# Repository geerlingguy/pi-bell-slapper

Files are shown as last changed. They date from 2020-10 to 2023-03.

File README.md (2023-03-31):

# Raspberry Pi Bell Slapper

_a.k.a. "The King of Ding", harbinger of the Internet of Dings_



<p align="center">
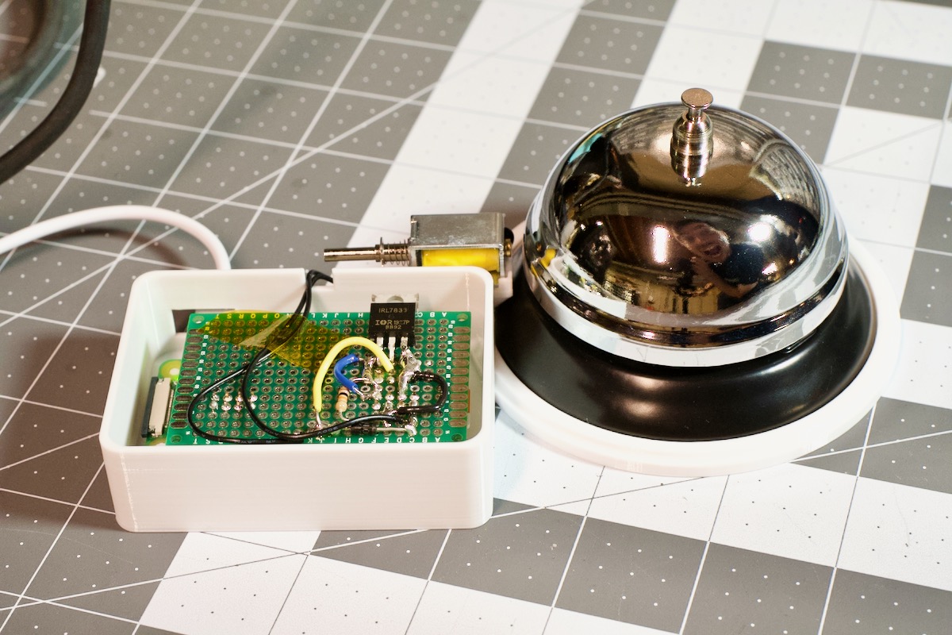
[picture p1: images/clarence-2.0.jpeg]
Clarence 2.0 - Raspberry Pi Bell Slapper
  
</p>

Why? I need a Raspberry Pi to slap a bell in response to a particular trigger.

In my case, it's for a radiothon. When a nonprofit community radio station gets a phone call, you can hear the phone in the background. When they get an online donation, you hear nothing.

Something is better than nothing, so I made this project, which slaps a bell upon a triggering condition.

## Is there a video of the build process?

Why, yes! How did you know?

Watch these videos for more on the build:

  - [The Raspberry Pi Internet of Dings Notification Bell](https://www.youtube.com/watch?v=o5wOzNzShrA) (June 2021 - "Clarence 2.0")
  - [The Raspberry Pi Bell Slapper - a software-controlled bell](https://www.youtube.com/watch?v=Etr7uIL9spg) (December 2020 - "Bell Slapper Mark I")

## How is the bell slapped?

I thought you'd never ask!

The bell is hit by a solenoid, specifically the [uxcell 4.5V mini Push-Pull Solenoid](https://amzn.to/2UkcLvh) I bought from Amazon.

<p align="center">
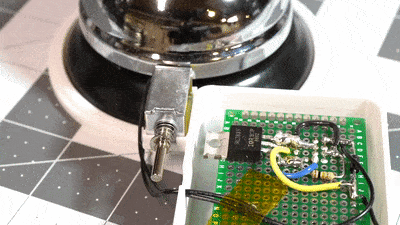
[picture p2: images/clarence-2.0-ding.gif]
Clarence 2.0 - Raspberry Pi Bell Slapper Solenoid Ding
  
</p>

The Pi tells the solenoid to trigger, and a little circuit I built as a hacked-together Pi HAT fires off a short pulse of energy to hit the side of the bell directly.

> In 2020, the original "Mark I" version of the bell was slapped quite differently, using a servo. Read the [Mark I README](README-Mark-I.md) for more information about _that_ version of the bell.

## What kind of bell does it slap?

I'm currently slapping a boring old call bell. [This call bell](https://amzn.to/3iCUL5F). But any bell you could mount to be slapped would work.

## How do I slap a bell?

I'm glad you asked! You'll need to gather some parts and solder together a little control circuit, since the Pi can't drive a 1A solenoid directly through a GPIO pin.

### Parts Needed

  - [Raspberry Pi Zero W](https://www.raspberrypi.org/products/raspberry-pi-zero-w/)
  - [Micro USB Power adapter](https://amzn.to/3zGpCrL)
  - [5V Push-Pull Solenoid](https://amzn.to/3cYFxI2)
  - [Double-sided Prototyping board](https://amzn.to/3zTqrxE)
  - [IRL7833PBF MOSFET Transistor - 30V 150A](https://amzn.to/3iYr3Mj)
  - [1A 50V Diode](https://amzn.to/3wNcJtY)
  - 10K Ohm Resistor
  - [Electronics hook-up wire](https://amzn.to/3xEUxCS)
  - [2x4 8-pin female headers](https://amzn.to/3vLDa1O)

### Tools Needed

These are the tools I used to put everything together (though you can use any suitable substitute):

  - [Weller WES51 Soldering Station](https://amzn.to/3iUX6g8)
  - [Adjustable Circuit board holder](https://amzn.to/35CrgNo) (not necessary but helpful)
  - [Ender 3 v2 3D Printer](https://amzn.to/3xGxojo)

### Assembly

Check out [this circuit diagram on Circuito.io](https://www.circuito.io/app?components=9443,11015,200000):

<p align="center">
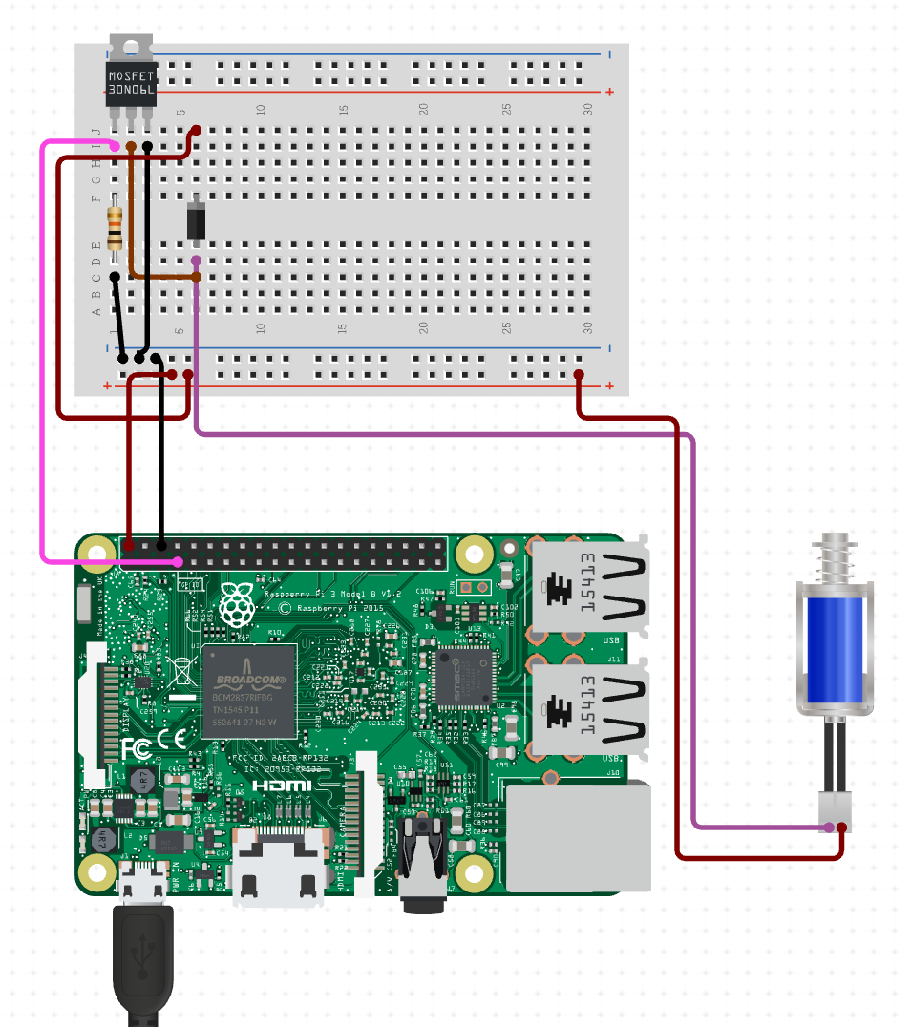
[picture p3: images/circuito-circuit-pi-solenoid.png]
Raspberry Pi GPIO 4 Solenoid control circuit
  
</p>

You could just stick everything into a breadboard like it's laid out in that diagram, but I decided to take a small protoboard and solder everything more permanently into a makeshift HAT that attaches to the top of the Pi Zero directly.

TODO: Add more detailed directions for wiring everything together—maybe also build a custom PCB?

## How do I contain this bell-slapping awesomeness?

I'm glad you asked. Over in the [`enclosure`](enclosure) directory, there are STL files for a case and lid. Print those on a 3D printer, mount everything inside, and you'll be good to go!

For the current design, I use friction and gravity to hold the Pi Zero and custom HAT in place, and superglue to hold in the solenoid.

The case design is derived from [@tenderlove's Analog Terminal Bell case](https://github.com/tenderlove/analog-terminal-bell/tree/master/case), and is modeled in OpenSCAD. The source files are also in the `enclosure` directory, should you like them.

## How do I tie email notifications to the bell slapper?

Well, now we're getting to the meat of it.

It's easy enough to slap a bell with your hand; there's no point in making a Raspberry Pi do it if you just want to slap the bell once or twice.

I built this project to monitor an email inbox. So I wrote a Python script, `email-check.py`. That python script does all the magic of translating "new email arrives" into "the bell has been resoundingly slapped".

To make this script work, you need to do two things on the Pi:

  1. Copy the `config.example.yml` file to a file named `config.yml`, and modify it with the email credentials for the account to be monitored.
  2. Make sure Pip is installed: `sudo apt install -y python3-pip`
  3. Run `python3 -m pip install imapclient pyyaml` to install required dependencies.

Then run `./email_check.py`, and prepare to be amazed! Or not, especially if it doesn't work.

> You might also need to install Pip, if you get an error on the `python3 -m pip` command. To do that, run `sudo apt install -y python3-pip`.

### How do I continuously check the email inbox?

Well now we're really getting somewhere useful!

For now, I'm just using cron. Fire up the ol' crontab editor (`crontab -l`) and add the following line:

```
* * * * * /home/pi/pi-bell-slapper/email_check.py
```

Then every minute the script will run!

> Note: If you have any errors, cron will email them to localhost (make sure you have something like `postfix` and `mailutils` installed to catch and read those emails). Other cron output goes into the syslog (check `/var/log/syslog`).

If you're using a Pi like the model A+, which doesn't have built-in WiFi, and you're using a cheap USB WiFi dongle to connect to the Internet, there's a chance it will go into a sleep mode after a minute or so—follow [these directions to stop the thing from sleeping](https://www.jeffgeerling.com/blogs/jeff-geerling/edimax-ew-7811un-tenda-w311mi-wifi-raspberry-pi).

## How do I also play a sound through a sound output?

The bell slapper can also play a sound when the bell is slapped, so you could have any other sound triggered upon a successful notification as well.

To enable this functionality, set `sound.enable` to `true` in your `config.yml` file, and provide the path to a sound file to play.

Next, install the dependencies required to play sounds:

```
$ pip3 install pygame
$ apt-get install libsdl2-mixer-2.0-0
```

You also have to tell the play_sound script the right audio device to use, so check what sound devices are present on your system:

```
$ cat /proc/asound/modules
 1 snd_usb_audio
```

In this case, I'm using a USB sound card, and it's identified as device number `1`.

Create a file with `sudo nano /etc/asound.conf` with the contents:

```
pcm.!default {
        type hw
        card 1
}

ctl.!default {
        type hw
        card 1
}
```

Then verify it's working with:

```
$ speaker-test -c2 -twav -l7
```

You should hear some sound coming from the left and right speakers. If you do, this means the entire audio setup is working properly, and the `play_sound.py` script should work:

```
$ ./play_sound.py
```

The project comes with a default `ding.wav` file that sounds exactly like the call bell that is physically struck by the solenoid. You can use any compatible audio file, though; just edit the `file` path in `config.yml`.

If sound is enabled, the sound will also play any time the `email_check.py` script detects an email matching the specified contitions.

## How do I control the Bell Slapper via a Web UI?

This project contains a tiny PHP web application that lets you slap the bell from anywhere you can reach the Pi (usually just on the local network). All you need is a phone, tablet, or computer with a web browser.

If the hostname of the Pi is `bell-slapper.local`, just visit that URL in your browser, and voila! You won't see anything!

That's because to get it working, you'll need to install PHP and Apache first:

```
# Install PHP and Apache.
$ sudo apt update
$ sudo apt install apache2 php php-yaml -y

# Verify that PHP was installed.
$ php -v
PHP 7.3.31-1~deb10u1 (cli)
```

Then add an Apache VirtualHost defining the path to this project's web directory:

```
$ sudo nano /etc/apache2/sites-enabled/pi-bell-slapper.conf

# Paste the following inside that file and save it:
<VirtualHost *:80>
    DocumentRoot "/home/pi/pi-bell-slapper/web"
    ServerName bell-slapper.local
    DirectoryIndex index.php
    <Directory /home/pi/pi-bell-slapper/web>
        Require all granted
    </Directory>
</VirtualHost>
```

Finally, add the Apache user to the GPIO group so it can run the bell slapper script, and then restart Apache:

```
$ sudo usermod -a -G gpio www-data
$ sudo systemctl restart apache2
```

Now visit `bell-slapper.local` in a browser, and ding away to your heart's content!

> If you need to update the hostname of the Pi, run `sudo raspi-config`, go to System Options > Hostname, and update the hostname (e.g. `bell-slapper`). Then reboot, and it should be accessible at `bell-slapper.local`.

## Were you inspired by anyone?

Of course I was inspired. You don't think I came up with all this on my own, did you? Alex Meub's [Office Bell Ringer](https://alexmeub.com/office-bell-ringer/) was my inspiration. Go read that post if you want to discover how I was inspired.

The enclosure design was inspired by Aaron Patterson's [Analog Terminal Bell](https://github.com/tenderlove/analog-terminal-bell).

Why are you so interested in _my_ inspiration? Go find your own.

## Is this project sponsored?

Technically, no. But monetarily, yes! Special thanks to the folks at [WTI](https://www.wti.com) ([@wtinetworkgear](https://github.com/wtinetworkgear)) for sponsoring this project.

You can sponsor too, via [GitHub Sponsors](https://github.com/sponsors/geerlingguy)!

## Who are you?

I'm [Jeff Geerling](https://www.jeffgeerling.com), and I approve of this repository.

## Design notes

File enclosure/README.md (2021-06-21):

# Bell Enclosure

This case was designed with [OpenSCAD](http://openscad.org), and STL files are also included here so you can print the enclosure parts directly.

The enclosure design is based on [@tenderlove's Analog Terminal Bell](https://github.com/tenderlove/analog-terminal-bell/tree/master/case).

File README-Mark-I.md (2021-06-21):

## Mark I - "Ye Olde Bell Slapper"

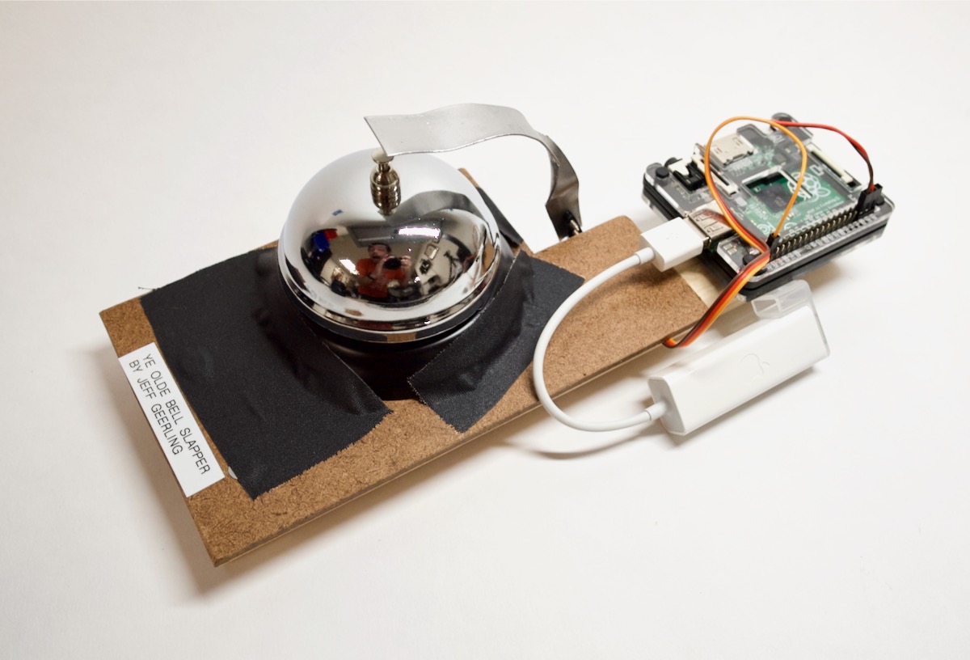
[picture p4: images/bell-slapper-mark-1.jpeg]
Raspberry Pi Bell Slapper - Mark I


The original 2020 version of the notification bell was slapped using one of a pair of [MG90S Micro Servos](https://amzn.to/2I6sZSC) I bought from Amazon. The Pi tells the servo to go, the servo hits the bell with a little armature, and there you have it.

Well now, here's where it gets interesting. I thought I'd share all the code and tell you how it's done. That's why you're reading this, isn't it?

  1. Clone this repository to your Pi: `git clone -b 1.3.0 https://github.com/geerlingguy/pi-bell-slapper.git`
  1. Run `python3 -m pip install RPi.GPIO` to install required dependencies.
  1. Plug in the following wires on the servo motor (see illustration below):

     1. Red wire to 5V power (pin 4)
     1. Brown wire to ground (pin 6)
     1. Orange wire to GPIO 21 (pin 40)

  1. Change into this directory (`cd pi-bell-slapper`) and run the command `./bell_slap.py`.
  1. Wait a second, and you'll see the motor spin, then reverse back to its original position.

Here's an illustration of the servo connections:

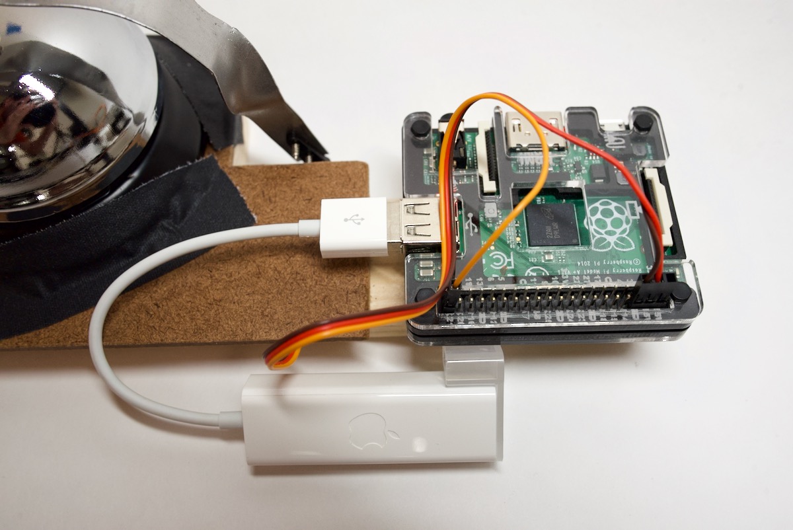
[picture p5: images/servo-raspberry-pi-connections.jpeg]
Servo motor Pi connections


> Note: The servo's wires come preinstalled into a 3-pin dupont female connector. You can use a tiny thing to pry up the release on the orange pin barrel connector, and slide that out. Then slide it into a separate 1-pin dupont female connector, and voila! You can then plug that orange wire directly into pin 40.

### But how do I mount this contraption to _actually_ slap a bell?

Well... it's a little more complicated because to slap a real bell, you have to mount the servo motor to something solid, build a little armature to slap the bell, mount the bell so it doesn't move when slapped.

You can see my franken-build up at the top of this README. It ain't pretty, but she's got it where it counts.

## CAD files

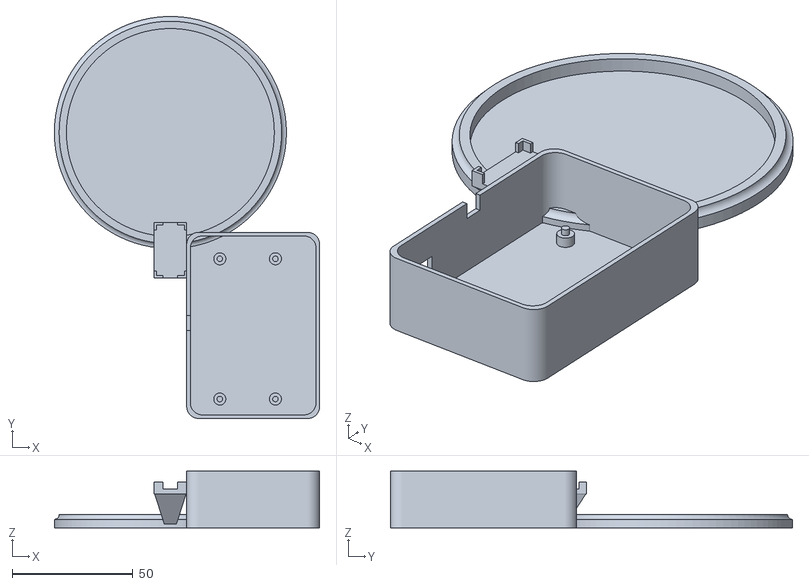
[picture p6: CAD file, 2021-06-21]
enclosure/case.stl
109.7 x 166.3 x 23.4

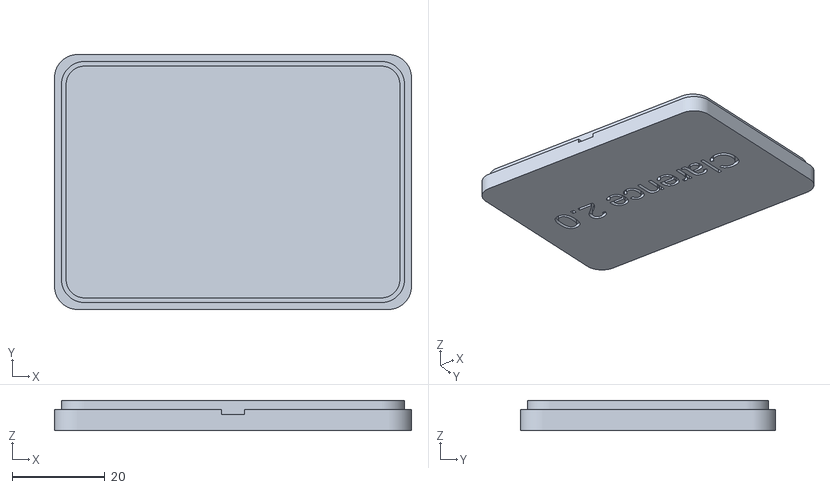
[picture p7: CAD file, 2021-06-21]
enclosure/lid.stl
77.0 x 55.0 x 6.50

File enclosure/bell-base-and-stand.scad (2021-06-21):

use <solenoid-stand.scad>
use <solenoid-mount.scad>
use <pcb.scad>
use <bell-base.scad>

module BellAndSolenoidStand(pcb = true) {
  plate_thickness = 1.5;
  bell_bottom_diameter = 86;
  bell_bottom_radius = bell_bottom_diameter / 2;
  bell_diameter = 72;
  bell_radius = bell_diameter / 2;

  fillet_height = 4;
  bottom_ridge_x = fillet_height + 1;
  to_bell_z = 16.5;
  bell_ridge_z = 6;
  solenoid_x = 11;
  solenoid_y = 20.5;
  solenoid_mount_wall_thickness = 1;

  outer_radius = bell_bottom_radius + bottom_ridge_x;

  max_overhang = bell_bottom_radius - bell_radius;
  distance_from_bell_to_solenoid_case = 2.5;
  overhang = max_overhang - distance_from_bell_to_solenoid_case;


  // align the center of the bell ridge with the center of the solenoid
  // solenoid_mounting_z should be the bottom of the solenoid
  post_bottom_y = ((solenoid_y / 2) - (bell_bottom_radius - bell_radius)) + 1;

  BellBase(plate_thickness, bell_bottom_diameter, fillet_height);

  translate([0, (-(bell_bottom_radius + (solenoid_y / 2))) + overhang, plate_thickness]) {
    solenoid_z = 12;

    post_bottom_thickness = fillet_height + 1;
    center_of_bell_ridge_z = to_bell_z + (bell_ridge_z / 2);
    solenoid_mounting_z = center_of_bell_ridge_z - (solenoid_z / 2);

    echo(outer_radius);
    SolenoidStand(solenoid_mounting_z - solenoid_mount_wall_thickness, overhang + solenoid_mount_wall_thickness, bottom_ridge_x, outer_radius);
    translate([0, 0, solenoid_mounting_z - solenoid_mount_wall_thickness])
      SolenoidMount();
  }

  if (pcb) {
    translate([((48 + 2 + plate_thickness + solenoid_x + 2) / 2) + 2, -(bell_bottom_radius + ((71.5 + 2 + plate_thickness) / 2)) + 0.7, 0])
      rotate(90)
      PCBCase(plate_thickness, plate_thickness, 3);
  }
}

BellAndSolenoidStand();

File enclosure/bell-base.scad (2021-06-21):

module BellBase(plate_thickness, bell_bottom_diameter, fillet_height) {
  bell_bottom_radius = bell_bottom_diameter / 2;
  bottom_ridge_x = fillet_height + 1;

  translate([0, 0, plate_thickness]) {
    color("Violet")
      translate([0, 0, -plate_thickness])
      linear_extrude(height = plate_thickness)
      circle(d = bell_bottom_diameter + (2 * bottom_ridge_x));

    color("Olive")
      rotate_extrude()
      translate([bell_bottom_radius, 0, 0]) {
        union() {
          square(size = [1, fillet_height]);
          translate([1, 0, 0]) {
            intersection() {
              square(fillet_height * 2);
              difference() {
                square(fillet_height * 2, center=true);
                translate([fillet_height, fillet_height]) circle(2);
              }
            }
          }
        }
      }
  }
}

BellBase(1.5, 86, 4);

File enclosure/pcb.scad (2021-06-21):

module Pegs(height, pin_diameter) {
  $fn = 90;
  pcb_thickness = 1.9;

  for (i = [-1.05, 0.95]) {
    for (j = [-0.8, 1.2]) {
      translate([i * (58 / 2), j * (23 / 2), 0]) {
        linear_extrude(height)
          circle(r = 2.5);
        linear_extrude(height + pcb_thickness)
          circle(d = pin_diameter);
      }
    }
  }
}

module PCBLid(top_thickness, wall_thickness) {
  pcb_padding = 2;
  pcb_x = 72 + pcb_padding;
  pcb_y = 50 + pcb_padding;
  radius = 5;
  pcb_thickness = 1.9 + 20; // pcb + components
  lid_height = 3;

  lip_height = 2;
  outer_lid_x = ((pcb_x + (wall_thickness * 2)) - (radius * 2));
  outer_lid_y = ((pcb_y + (wall_thickness * 2)) - (radius * 2));

  $fn = 90;
  difference() {
    union() {
      // inner lip
      linear_extrude(lid_height + top_thickness + lip_height)
        minkowski() {
          circle(r = radius);
          square(size = [pcb_x - (radius * 2), pcb_y - (radius * 2)], center = true);
        }

      // Outer
      color("green")
      linear_extrude(lid_height + top_thickness)
        minkowski() {
          circle(r = radius);
          square(size = [outer_lid_x, outer_lid_y], center = true);
        }
    }

    translate([0, 0, top_thickness])
    linear_extrude(pcb_thickness + 3) // Add 1 so it looks nice in preview
      minkowski() {
        circle(r = radius - 1);
        square(size = [pcb_x - (radius * 2), pcb_y - (radius * 2)], center = true);
      }

    for (i = [-1, 1]) {
      color("red")
        translate([0, i * ((outer_lid_y + (radius * 2)) / 2) - (i * (1 / 2)), (lid_height + top_thickness) - 1])
        linear_extrude(1)
        square(size = [5, 2], center = true);
    }

    mirror([1,0,0])
        translate([0,0,-.001])
            linear_extrude(1)
                text("Clarence 2.0", font = f, halign = "center", valign = "center", size = 8);
  }
}

module PCBCase(bottom_thickness, wall_thickness, peg_height = 3, pin_diameter = 2.3) {
  pcb_padding = 2;
  pcb_x = 72 + pcb_padding;
  pcb_y = 50 + pcb_padding;

  usb_height = 8;
  usb_width  = 14;

  radius = 5;
  pcb_thickness = 1.9 + 20; // pcb + components

  translate([0, 0, bottom_thickness]) {
    difference() {
      $fn = 90;
      //translate([0, 0, -bottom_thickness])
      translate([0, 0, -bottom_thickness])
        linear_extrude(bottom_thickness + pcb_thickness)
        minkowski() {
          circle(r = radius);
          square(size = [((pcb_x + (wall_thickness * 2)) - (radius * 2)), ((pcb_y + (wall_thickness * 2)) - (radius * 2))], center = true);
        }

        linear_extrude(pcb_thickness + 1) // Add 1 so it looks nice in preview
        minkowski() {
          circle(r = radius);
          square(size = [pcb_x - (radius * 2), pcb_y - (radius * 2)], center = true);
        }

      // Wire hole
      translate([((pcb_x - pcb_padding) / 2) - 35, ((pcb_y + wall_thickness) / 2), peg_height + 14])
        color("blue")
        linear_extrude(6)
        // Add 1 so it looks nice in preview
        square(size = [6, wall_thickness + 1], center = true);

      // USB hole
      translate([((pcb_x - pcb_padding) / 2) - 61, ((pcb_y + wall_thickness) / 2), peg_height + 1])
        color("blue")
        linear_extrude(usb_height)
        // Add 1 so it looks nice in preview
        square(size = [usb_width, wall_thickness + 1], center = true);

    }

    Pegs(peg_height, pin_diameter);
  }
}

PCBCase(1.5, 1.5);
//PCBLid(1.5, 1.5);

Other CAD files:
enclosure/solenoid-mount.scad
enclosure/case.scad
enclosure/solenoid-stand.scad

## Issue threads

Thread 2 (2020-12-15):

Consider a redesign using a spring-return / push-pull solenoid

geerlingguy, 2020-12-15:
Something like the [Push Pull Type Electric DC Solenoid](https://amzn.to/2KuN71H); basically mount the solenoid inside the bell, so I can have the Pi underneath, the solenoid on top, and ding the bell from the inside. So it's just a bell with a little box underneath. Maybe a good time to consider switching to the Pi Zero W, too!

geerlingguy, 2020-12-15:
(Idea from comment: https://www.youtube.com/watch?v=Etr7uIL9spg&lc=UgxKTLrzPYfF4dLlNcR4AaABAg.9HHklQ8r4_v9HI7jTzobpe)

geerlingguy, 2021-06-13:
Going to try my luck with this soon. I have a solenoid, but forgot to order a second call bell since the first is still in continuous operation :)

geerlingguy, 2021-06-13:
A couple more things I've seen recently, for inspiration:

  - [How Doorbells Work](http://crisp.southernct.edu/wp-content/uploads/2016/08/How-Does-a-Doorbell-work.pdf)
  - [Email Notification Bell](https://www.instructables.com/Email-notification-bell/)

geerlingguy, 2021-06-13:
To provide the ~600mA current at 5V for the solenoid, I'll probably need to power it off the Pi's 5V rail instead of through GPIO directly, since [according to this answer](https://raspberrypi.stackexchange.com/a/9299), the 3.3V rail can only drive ~50mA... more research required.

geerlingguy, 2021-06-13:
This circuit looks like a good guide: [Pi 3 B+ 5v solenoid push-pull](https://www.circuito.io/app?components=9443,11015,200000).

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

geerlingguy, 2021-06-16:
I'm also needing to design a new enclosure/case for the thing... was going to do some measurements and start building things up by hand... but it looks like @tenderlove already did some of that work for me: https://github.com/tenderlove/analog-terminal-bell/tree/master/case

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

I'm thinking of modifying that design to house everything below/inside the bell... if I can route the solenoid that way.

geerlingguy, 2021-06-18:
Some code:

```python
import RPi.GPIO as GPIO
import time

# Use GPIO pin numbers instead of physical pin numbers.
GPIO.setmode(GPIO.BCM)

# Set GPIO pin 4 as the output.
GPIO.setup(4, GPIO.OUT)

# Set GPIO 4 high for .1s and then back low.
GPIO.output(4, GPIO.HIGH)
time.sleep(0.1)
GPIO.output(4, GPIO.LOW)

# Cleanup.
GPIO.cleanup()
```

Save that to a file like `ding.py` and also make sure your user has permissions to control GPIO with `sudo adduser pi gpio` and logging out and logging back in (else you'll get a warning `RuntimeError: Not running on a RPi!`).

Then run:

```
python ding.py
```

This should light up GPIO pin 4, and cause a ding, using the circuit in this comment: https://github.com/geerlingguy/pi-bell-slapper/issues/2#issuecomment-860276630

geerlingguy, 2021-06-18:
It verks!

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

geerlingguy, 2021-06-18:
Just noting this for myself: For the Pi Zero W, it requires 32-bit Pi OS (since the CPU is not 64-bit capable), and it only works on 802.11b/g/n at 2.4 GHz (no 5 GHz networking). With _that_ out of the way, I can get it tested and working now :)

geerlingguy, 2021-06-18:
Next step: Learning OpenSCAD...

geerlingguy, 2021-06-19:
Almost everything is perfect... but the USB port in the current version (above commit) is a hair off center to the right. Have to move it back left so larger USB cables fit through correctly.

Someday if I design a proper PCB / HAT, I can make the tolerances much slimmer. For now it works with a simple small hacked-together protoboard.

geerlingguy, 2021-06-20:
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

Closed 2021-06-21.

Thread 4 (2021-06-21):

Fix alignment of micro USB power jack

geerlingguy, 2021-06-21:
I need to move the cutout about 1.5mm down, and 2mm left.

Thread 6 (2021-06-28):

Create a PCB / 'HAT' that fits inside the Pi Zero footprint

geerlingguy, 2021-06-28:
I'd like to make a for-real PCB for this circuit—ideally with the circuits mounted underneath so everything fits within the footprint of a Pi Zero and is only the height of the GPIO header plus a PCB. This would allow a much more compact mounting solution, and the possibility of putting everything under the bell itself maybe...

Someone on Twitter hacked up a quick concept PCB: https://oshwlab.com/magic.blue.smoke/pizero_solenoid

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

I'd have to verify it works, but that could be the ticket.

geerlingguy, 2021-07-02:
Over on YouTube, [billiamthesecond pointed out](https://www.youtube.com/watch?v=o5wOzNzShrA&lc=Ugy1OsjJEaRukHJBBzp4AaABAg.9PGMU3-qOSt9PJ2LK2VHA8) this project: [Arduino desk bell notifications](https://www.billiam.org/2021/03/08/desk-bell-alerts). It stuffs an Arduino inside the bell.

Might be able to modify the project to use an ESP or even a Pico with WiFi, and get it all inside...

geerlingguy, 2021-07-02:
And that linked to this [Kickstarter alert bell](https://aaronparecki.com/2017/11/13/5/kickstarter-desk-bell).

maitesam, 2021-07-04:
[Pi0 Bell slaper.zip](https://github.com/geerlingguy/pi-bell-slapper/files/6759697/Pi0.Bell.slaper.zip)
Hi Jeff, Check these files out..
In the zip, you'll find complete hardware design, manufacturing files, MCAD and source files. I Hope you'll like it..
Thank you

maitesam, 2021-07-04:
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

A bit of explaination on the design.
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

Please let me know if you feel the need of any changes in the board.
Thanks

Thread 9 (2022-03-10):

Fix mobile viewport for web UI

geerlingguy, 2022-03-10:
The web UI I added in https://github.com/geerlingguy/pi-bell-slapper/commit/b229be4477e39b6886e12ec0cba30863c165ac5a works great on desktop, but on mobile, I get a very narrow viewport and have to zoom in to use the interface:

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

I'm guessing Bootstrap has some way of making this responsive easily? Or am I missing a viewport setting in the HTML?

geerlingguy, 2022-03-10:
I was just missing:

```html
<meta name="viewport" content="width=device-width, initial-scale=1">
```

Inside the `<head/>` tag.

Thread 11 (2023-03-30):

Make it so you can ding and sing from the web UI

geerlingguy, 2023-03-30:
A few feature requests:

  - [x] Make the 'success' alert for dinging the bell dismissible.
  - [x] Make the 'success' alert automatically hide after 3 seconds.
  - [x] Add a 'Ding + Sound' button so you can both ding and play a sound if configured using `config.yml`

For deployment, I'll need to run `sudo apt install php-yaml` on my production Clarence unit, and pull all the latest data, then maybe restart `apache2`.

geerlingguy, 2023-03-30:
For the sound, I'm getting the following on a Pi I'm testing on that doesn't actually have a sound device integrated:

```
==> error.log <==
Failed to create secure directory (/var/www/.config/pulse): No such file or directory
Failed to create secure directory (/var/www/.config/pulse): No such file or directory
ALSA lib confmisc.c:767:(parse_card) cannot find card '0'
ALSA lib conf.c:4745:(_snd_config_evaluate) function snd_func_card_driver returned error: No such file or directory
ALSA lib confmisc.c:392:(snd_func_concat) error evaluating strings
ALSA lib conf.c:4745:(_snd_config_evaluate) function snd_func_concat returned error: No such file or directory
ALSA lib confmisc.c:1246:(snd_func_refer) error evaluating name
ALSA lib conf.c:4745:(_snd_config_evaluate) function snd_func_refer returned error: No such file or directory
ALSA lib conf.c:5233:(snd_config_expand) Evaluate error: No such file or directory
ALSA lib pcm.c:2660:(snd_pcm_open_noupdate) Unknown PCM default
Traceback (most recent call last):
  File "/home/pi/pi-bell-slapper/play_sound.py", line 32, in <module>
    play_the_sound()
  File "/home/pi/pi-bell-slapper/play_sound.py", line 23, in play_the_sound
    pygame.mixer.init()
pygame.error: No available audio device
```

I'm not sure if that first line is an error that would break anything or not (as I haven't tried this on the system that actually has the little USB sound card...), but it's something to keep in mind if it's not working. See https://unix.stackexchange.com/a/90025 for an example of a fix. I might just see about setting up pulseaudio settings for the Apache user, or system-wide.

geerlingguy, 2023-03-30:
Added the extra option and made everything supposedly work:

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

geerlingguy, 2023-03-31:
In production, getting:

```
Home directory not accessible: Permission denied
ALSA lib confmisc.c:767:(parse_card) cannot find card '0'
ALSA lib conf.c:4568:(_snd_config_evaluate) function snd_func_card_driver returned error: No such file or directory
ALSA lib confmisc.c:392:(snd_func_concat) error evaluating strings
ALSA lib conf.c:4568:(_snd_config_evaluate) function snd_func_concat returned error: No such file or directory
ALSA lib confmisc.c:1246:(snd_func_refer) error evaluating name
ALSA lib conf.c:4568:(_snd_config_evaluate) function snd_func_refer returned error: No such file or directory
ALSA lib conf.c:5047:(snd_config_expand) Evaluate error: No such file or directory
ALSA lib pcm.c:2565:(snd_pcm_open_noupdate) Unknown PCM default
Traceback (most recent call last):
  File "/home/pi/pi-bell-slapper/play_sound.py", line 32, in <module>
    play_the_sound()
  File "/home/pi/pi-bell-slapper/play_sound.py", line 23, in play_the_sound
    pygame.mixer.init()
pygame.error: ALSA: Couldn't open audio device: No such file or directory
```

Closed 2023-03-31.

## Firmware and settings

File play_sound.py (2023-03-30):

#!/usr/bin/env python3

# The sound player script.

from os import environ
environ['PYGAME_HIDE_SUPPORT_PROMPT'] = '1'

import pygame
import argparse


# Play the sound.
def play_the_sound(file='./ding.wav'):
    # Define optional command line argument.
    parser = argparse.ArgumentParser()
    parser.add_argument("-f", "--file", help="File")

    # Get arguments from command line (if supplied).
    args = parser.parse_args()
    sound_file = args.file if bool(args.file) else file

    # Play the sound.
    pygame.mixer.init()
    sound = pygame.mixer.Sound(sound_file)
    playing = sound.play()
    while playing.get_busy():
        pygame.time.delay(100)


if __name__ == '__main__':
    # This script is being executed directly. Play the sound right away!
    play_the_sound()

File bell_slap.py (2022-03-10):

#!/usr/bin/env python3

# The bell slapper script.

from time import sleep
import argparse
import RPi.GPIO as GPIO


# Slap the bell.
def slap_the_bell():
    try:
        # GPIO Pin where solenoid control circuit is connected.
        solenoid_pin = 4

        # Define optional command line arguments.
        parser = argparse.ArgumentParser()
        parser.add_argument("-c", "--count", help="Count (how many dings)")
        parser.add_argument("-i", "--interval", help="Interval between dings")

        # Get arguments from command line (if supplied).
        args = parser.parse_args()
        ding_count = int(args.count) if bool(args.count) else int('1')
        ding_interval = float(args.interval) if bool(args.interval) else float('1.0')

        # Don't allow dinging faster than every 0.05 seconds.
        if ding_interval < 0.05:
            ding_interval = float('0.05')
            print("Interval was reset to 0.05 to protect the circuit.")

        # Define the Pin numbering type and define Servo Pin as output pin.
        GPIO.setmode(GPIO.BCM)
        GPIO.setup(solenoid_pin, GPIO.OUT)

        # Bell slap loop.
        while (ding_count > 0):
            GPIO.output(4, GPIO.HIGH)
            sleep(0.01)
            GPIO.output(4, GPIO.LOW)
            sleep(ding_interval)
            ding_count -= 1

    except KeyboardInterrupt:
        print("User stopped script during execution.")

    finally:
        try:
            GPIO.cleanup()

        except NameError:
            pass


if __name__ == '__main__':
    # This script is being executed directly. Slap the bell right away!
    slap_the_bell()

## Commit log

2020-10-07 Update values for my motor's rotation.
2020-10-08 Issue #1: Add an email check Python script.
    [email-check.py]
2020-10-08 Issue #1: Connect the email_check to the bell_slap.
    [bell_slap.py, email_check.py]
2020-10-08 Read the correct thingamabob.
    [email_check.py]
2020-10-09 Fix the duty cycle of the servo so it gently slaps the dinger.
    [bell_slap.py]
2021-06-19 Issue #2: Add enclosure based on Analog Terminal Bell.
    [bell-base-and-stand.scad, bell-base.scad, case.scad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]
2021-06-19 Solenoid case enclosure updates for final dimensions.
    [bell-base-and-stand.scad, bell-base.scad, case.stl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]
2021-06-21 Update bell slap script for solenoid use.
2021-06-21 Fix lint issue with time import.
    [bell_slap.py]
2021-06-21 Add delay between bell slaps for solenoid, and fix up README.
    [email_check.py]
2021-06-24 Add circuit diagram from Circuito.
2021-07-01 Add 3D Printed case notes to main README.
2022-03-10 Fix flake8 Python lint issues.
    [bell_slap.py]
2022-03-10 Fix indentation to make flake8 happy.
    [play_sound.py]
2023-03-30 Issue #11: Make it so you can ding and sing from the web UI.
    [play_sound.py]
